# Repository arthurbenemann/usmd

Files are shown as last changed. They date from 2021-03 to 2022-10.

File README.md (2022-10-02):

# uSMD

## Board
usmdtop
usmdbot

## BOM
|Qty.|Rec. Qty.|DK Part Number |Manufacturer Part Number|Description |Reference |Unit Price|Extended Price|
|----|---|---|---|---|---|---|---|
|10  |15 |587-4850-1-ND |JMK021BJ103KK5W |CAP CER 10000PF 6.3V X5R 008004|C1 - C10 |0.53300 |$8.00 |
|1 |2 |754-2028-1-ND |APG0603SEC-E-TT |LED RED CLEAR 2SMD |D1 |0.43000 |$0.86 |
|1 |3 |118-CR01005-FW-1001GLFCT-ND|CR01005-FW-1001GLF |RES 1K OHM 1% 1/32W 01005 |R1 |0.10000 |$0.30 |
|1 |3 |YAG6214CT-ND |RC0100FR-0710ML |RES SMD 10M OHM 1% 1/32W 01005 |R2 |0.31000 |$0.93 |
|1 |2 |296-46430-1-ND |LMC555CTPX/NOPB |IC OSC SINGLE TIMER 3MHZ 8-USMD|U1 |1.34000 |$2.68 |
|1 |1 |36-3031-ND |3031 |BATTERY RETAINER COIN PC PIN |BT1 |0.61000 |$0.61 |
|1 |1 |P031-ND |CR-1025/BN |BATTERY LITHIUM 3V COIN 10MM |N/A |1.03000 |$1.03 |
|1 |3 |[6NPtd21R](https://oshpark.com/shared_projects/6NPtd21R)|uSMD-Rev1-PCB|uSMD OSHPARK PCB|N/A |0.50000 |$1.50 |
| | | | | | |**Total** |**$15.64** |

## Photos
uSMD and [misery challenge](https://github.com/aspro648/KiCad/tree/master/projects/Attiny/AttinyChallengeMisery) stacked up.
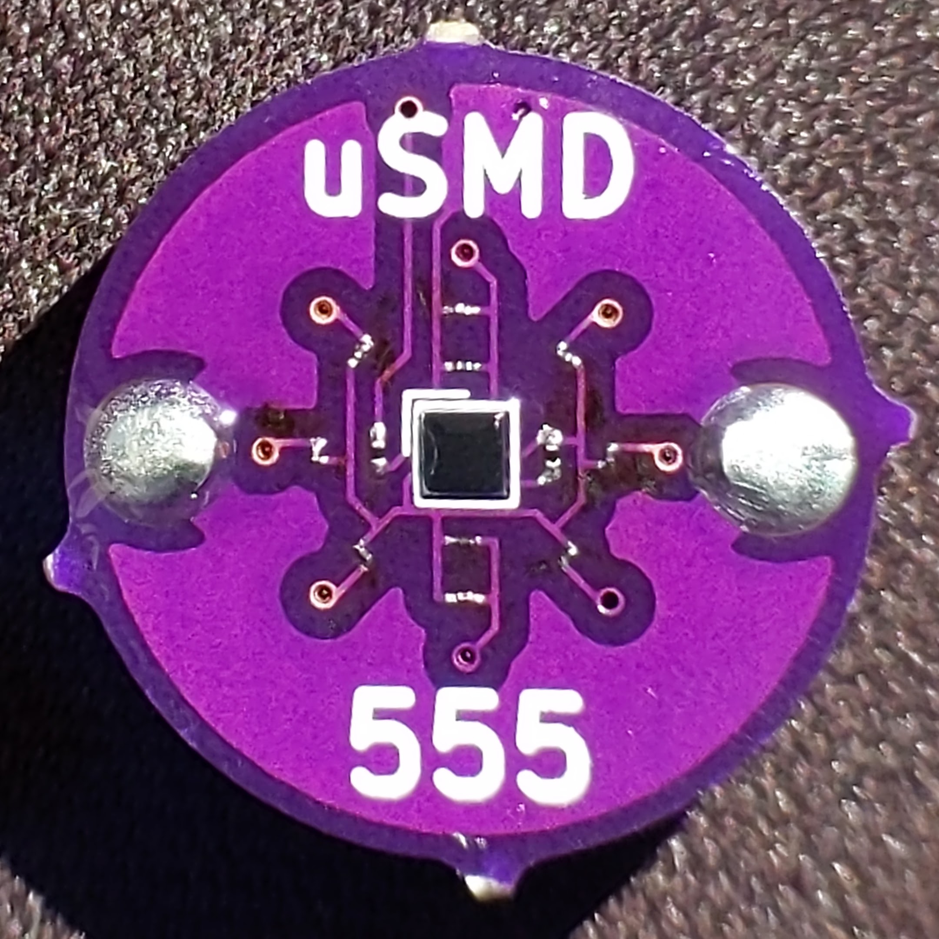
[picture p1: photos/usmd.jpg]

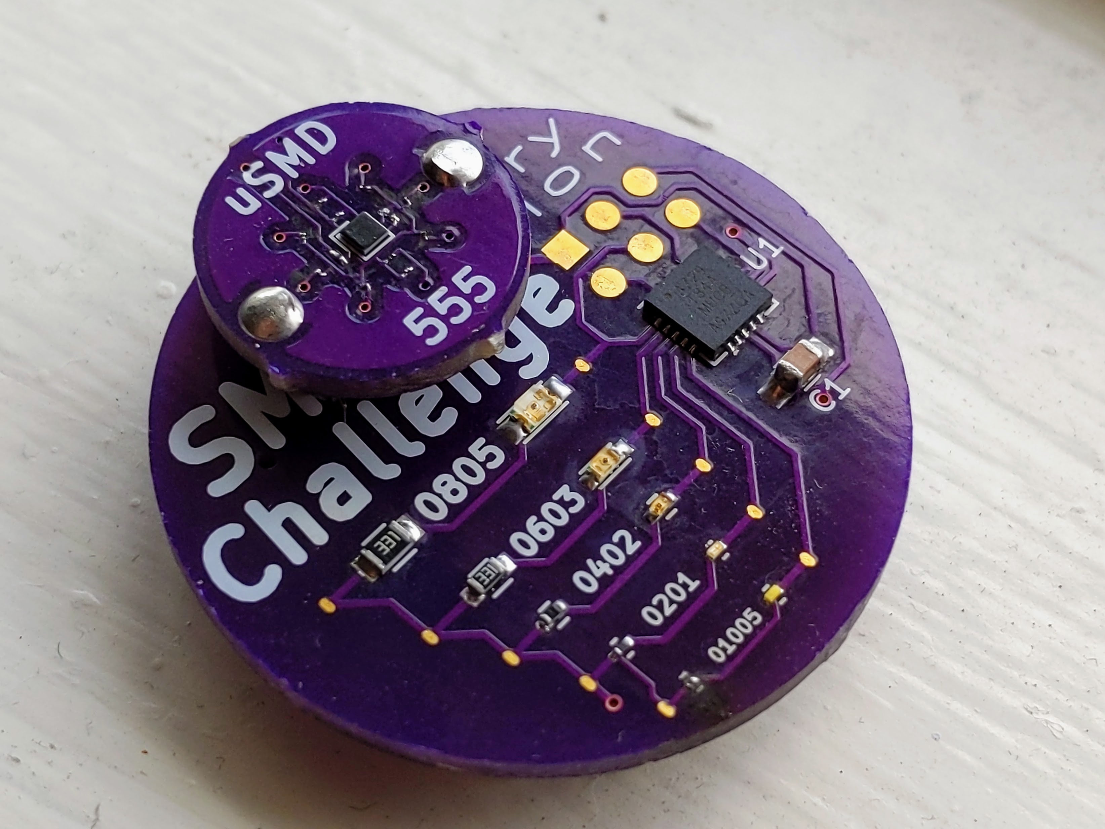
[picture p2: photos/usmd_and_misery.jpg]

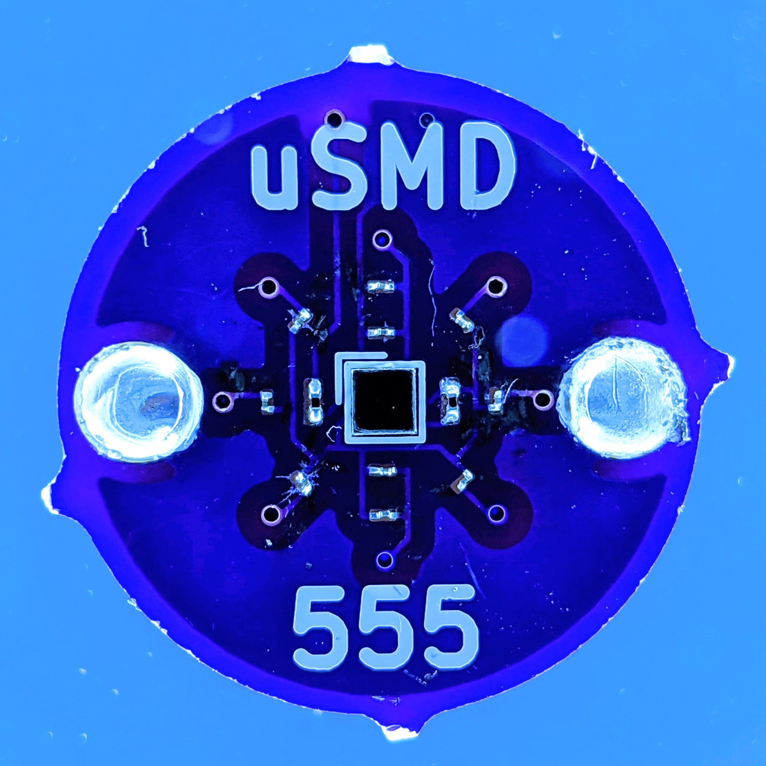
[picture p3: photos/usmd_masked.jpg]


USMD under microscope
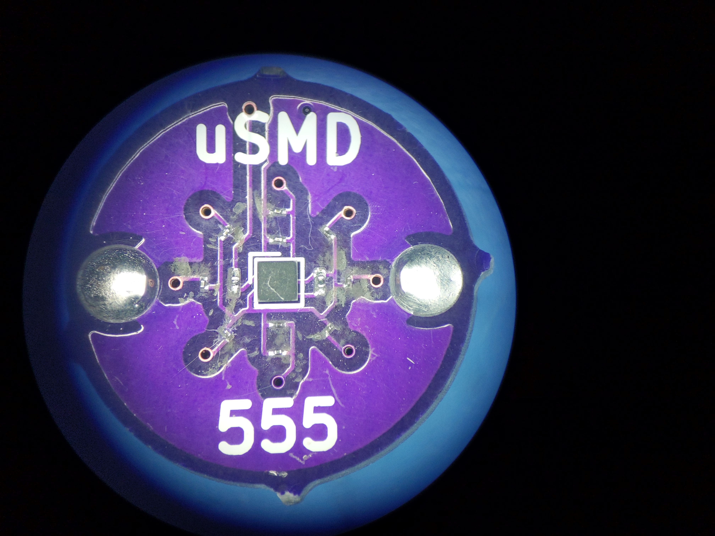
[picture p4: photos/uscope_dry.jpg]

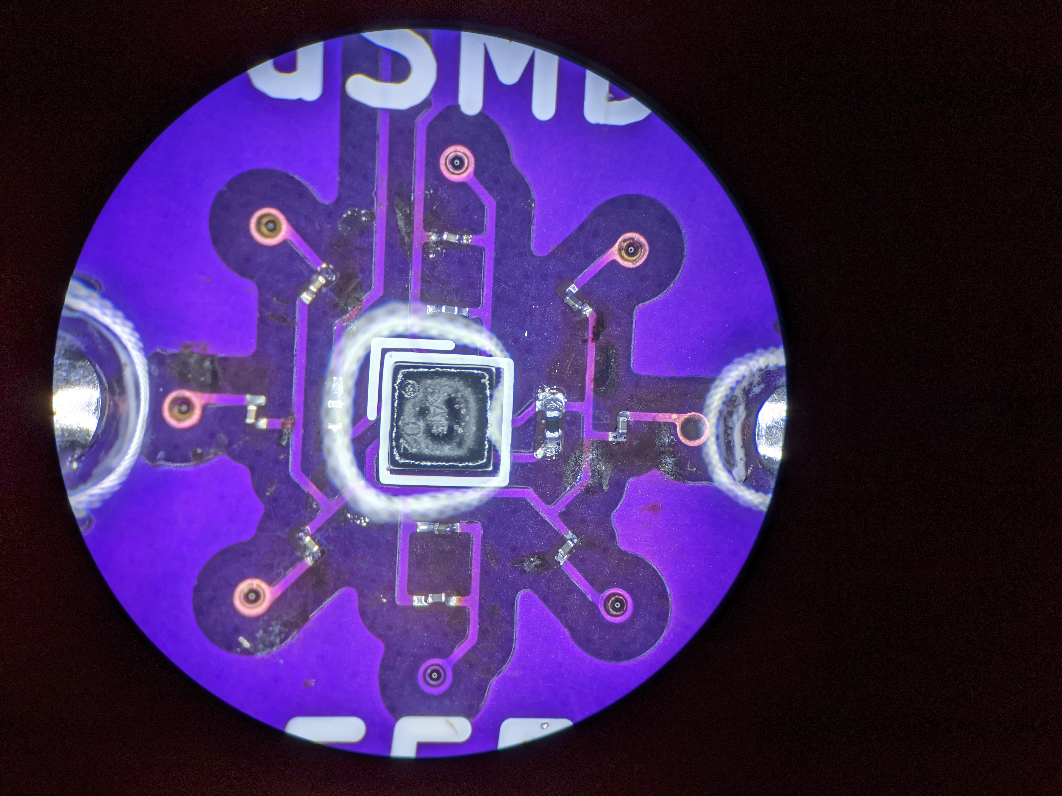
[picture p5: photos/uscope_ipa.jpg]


Size of an 08004 against a human hair
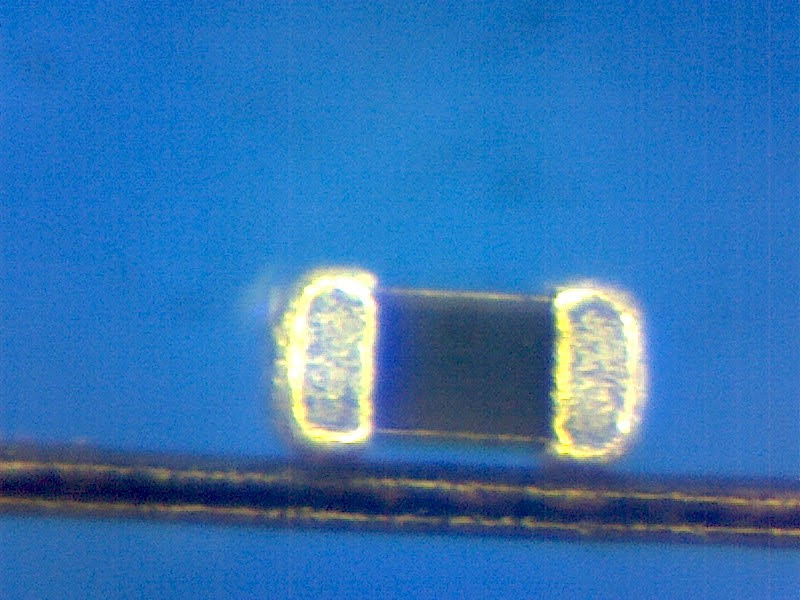
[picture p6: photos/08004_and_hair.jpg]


If all compoents are soldered properly LED should blink at ~1Hz:
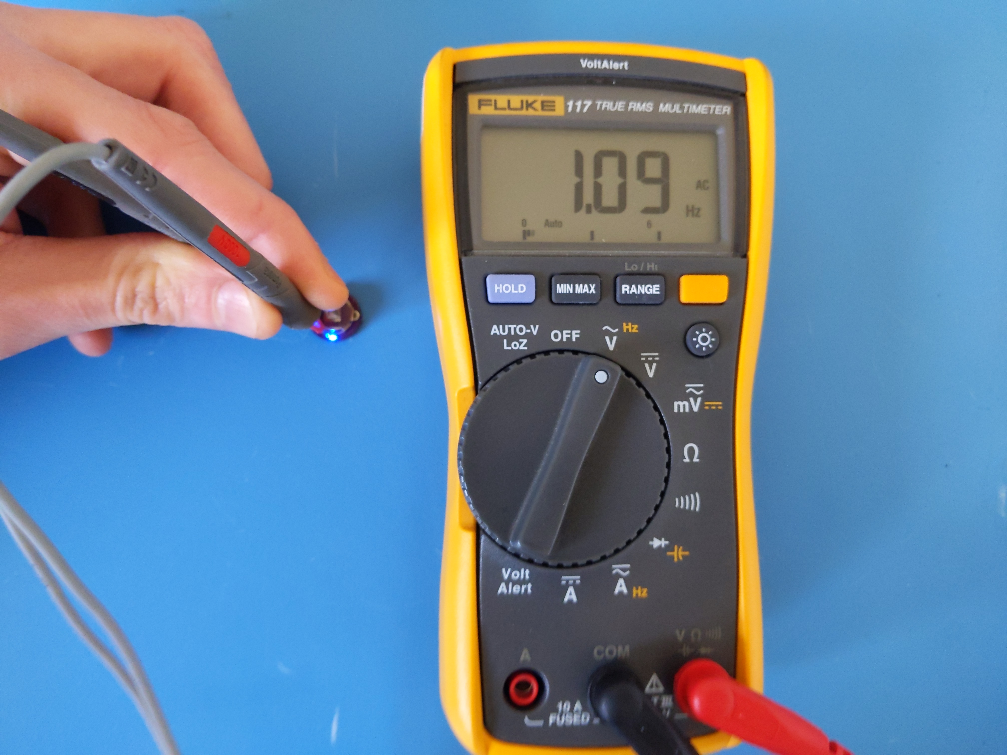
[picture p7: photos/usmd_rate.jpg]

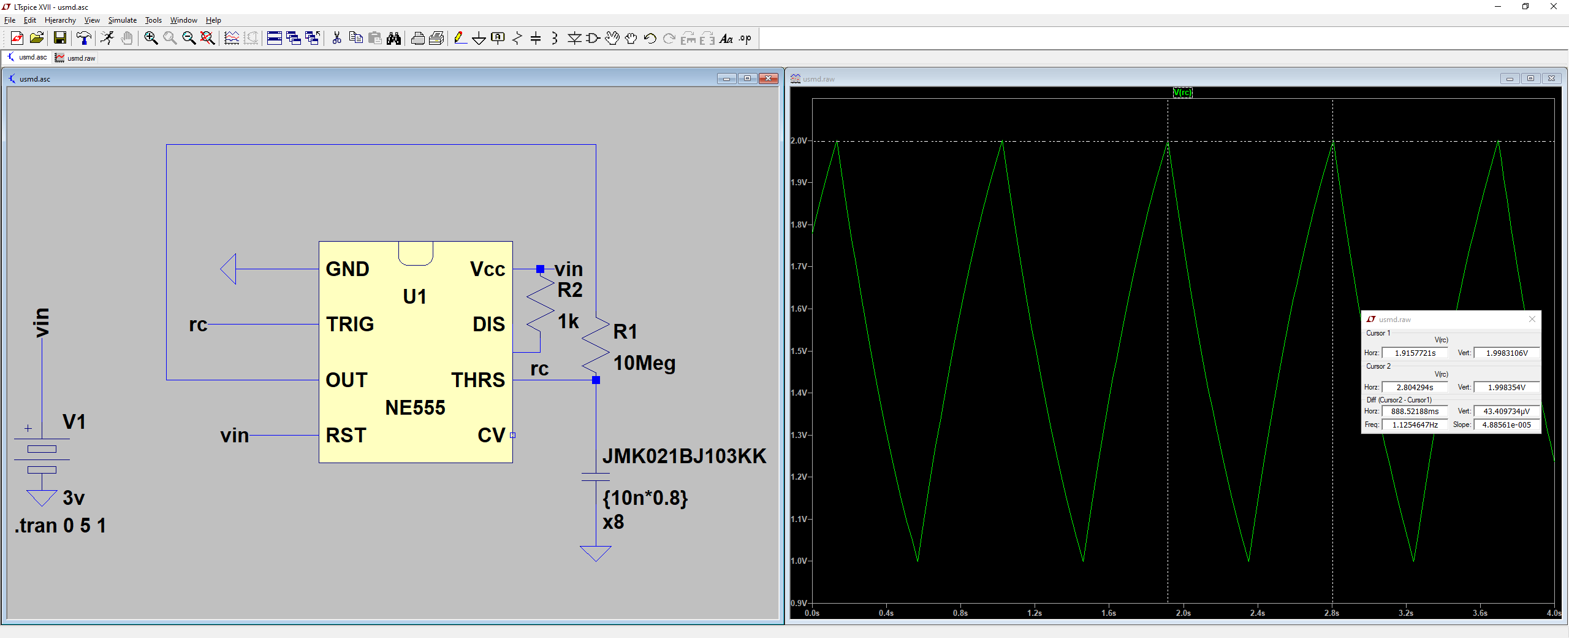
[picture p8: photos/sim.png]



## External
Marco Reps assembly on video, better than the original: https://www.youtube.com/watch?v=2vpTYaDGmCs&t=1451s

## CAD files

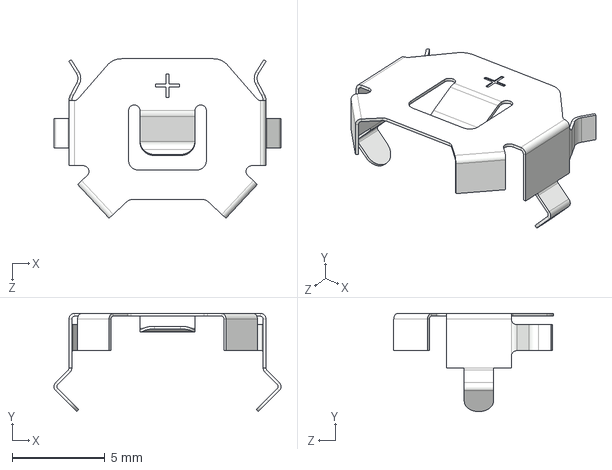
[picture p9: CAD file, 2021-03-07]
keystone-PN3031.STEP
12.2 x 5.29 x 8.59 mm

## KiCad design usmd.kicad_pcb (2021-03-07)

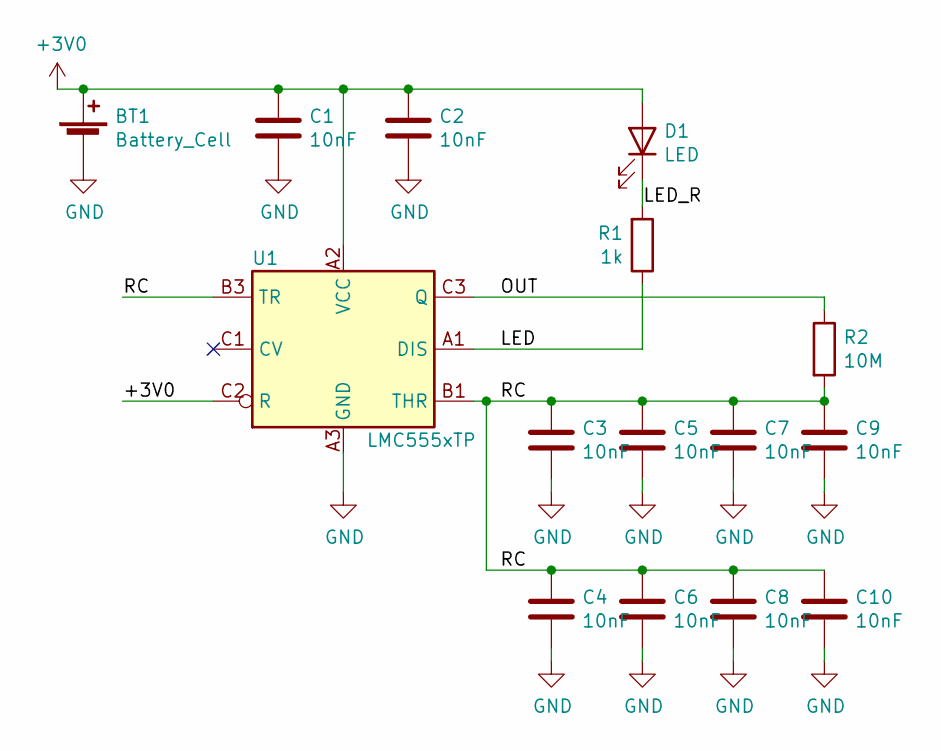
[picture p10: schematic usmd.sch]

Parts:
BT1: Battery_Cell; BatteryHolder_Keystone_3031_1x10mm; MPN 3031
C1, C2, C3, C4, C5, C6, C7, C8, C9, C10: 10nF; C_008004_0201Metric; MPN 587-4850-1-ND
D1: LED; LED_0201_0603Metric; MPN APG0603SEC-E-TT
R1: 1k; R_01005_0402Metric; MPN CR01005-FW-1001GLF
R2: 10M; R_01005_0402Metric; MPN ‎YAG6214CT-ND‎
U1: LMC555xTP; Texas_DSBGA-8_1.43x1.41mm_Layout3x3_P0.5mm; MPN LMC555CTPX/NOPB

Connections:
+3V0: BT1.1 (+), C1.1, C2.1, D1.2 (A), U1.A2 (VCC), U1.C2 (R)
/LED: R1.1, U1.A1 (DIS)
/LED_R: D1.1 (K), R1.2
/OUT: R2.1, U1.C3 (Q)
/RC: C3.1, C4.1, C5.1, C6.1, C7.1, C8.1, C9.1, C10.1, R2.2, U1.B1 (THR), U1.B3 (TR)
GND: BT1.2 (-), C1.2, C2.2, C3.2, C4.2, C5.2, C6.2, C7.2, C8.2, C9.2, C10.2, U1.A3 (GND)

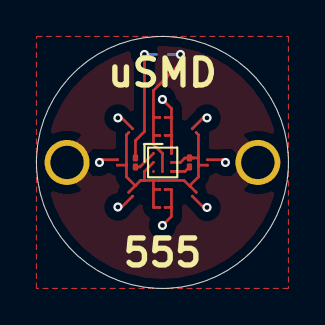
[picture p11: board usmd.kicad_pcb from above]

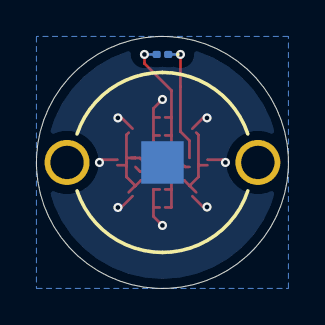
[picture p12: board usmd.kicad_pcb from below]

Board: 2 copper layers, 14.0 x 14.0 mm, 15 parts (2 on the bottom side), 6 nets.
